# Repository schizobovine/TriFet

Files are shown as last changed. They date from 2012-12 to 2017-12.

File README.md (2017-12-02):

TriFet Motor Driver
-------------------

All credit goes to [Ethan Zonca](http://protofusion.org/), who released the design as Open Source Hardware. Kudos, sir!

Original [TriFet Repository](http://protofusion.org/hg/TriFet/) (Mercurial)

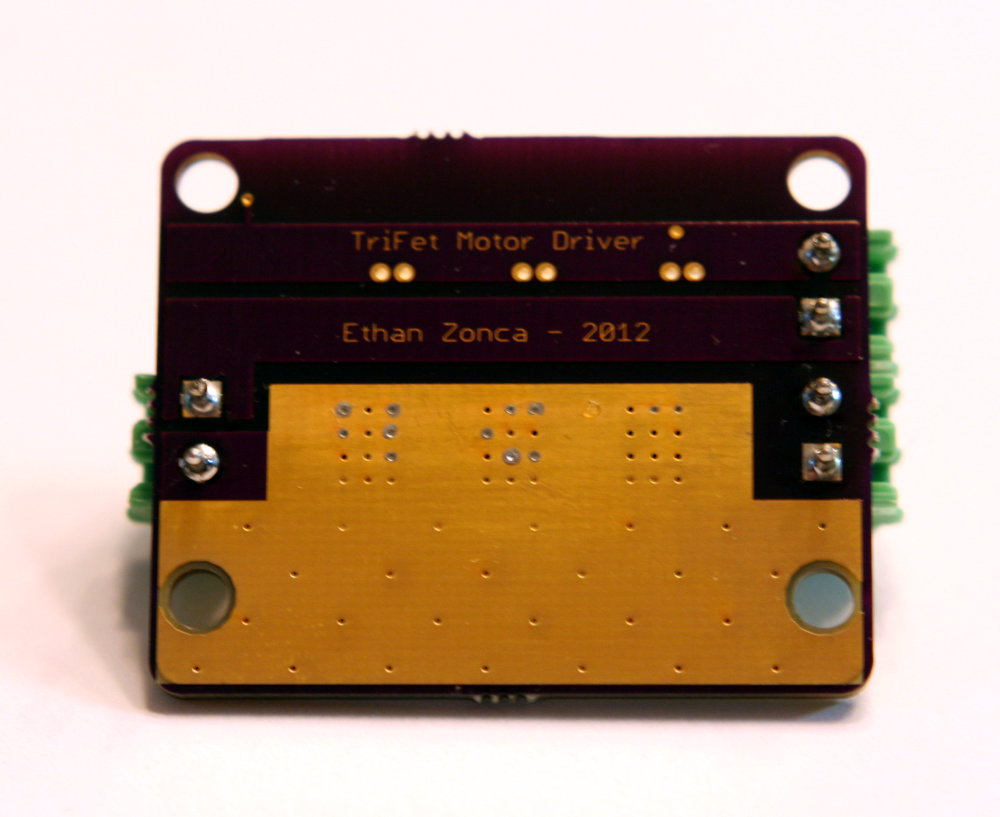
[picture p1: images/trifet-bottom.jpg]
TriFet Bottom

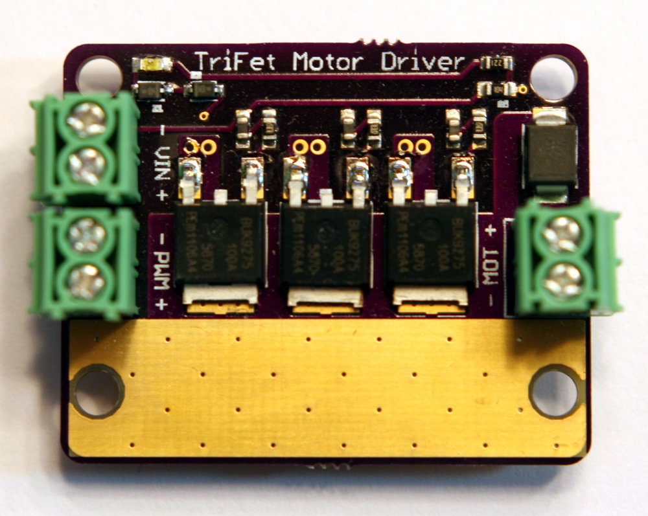
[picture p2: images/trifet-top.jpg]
TriFet Top

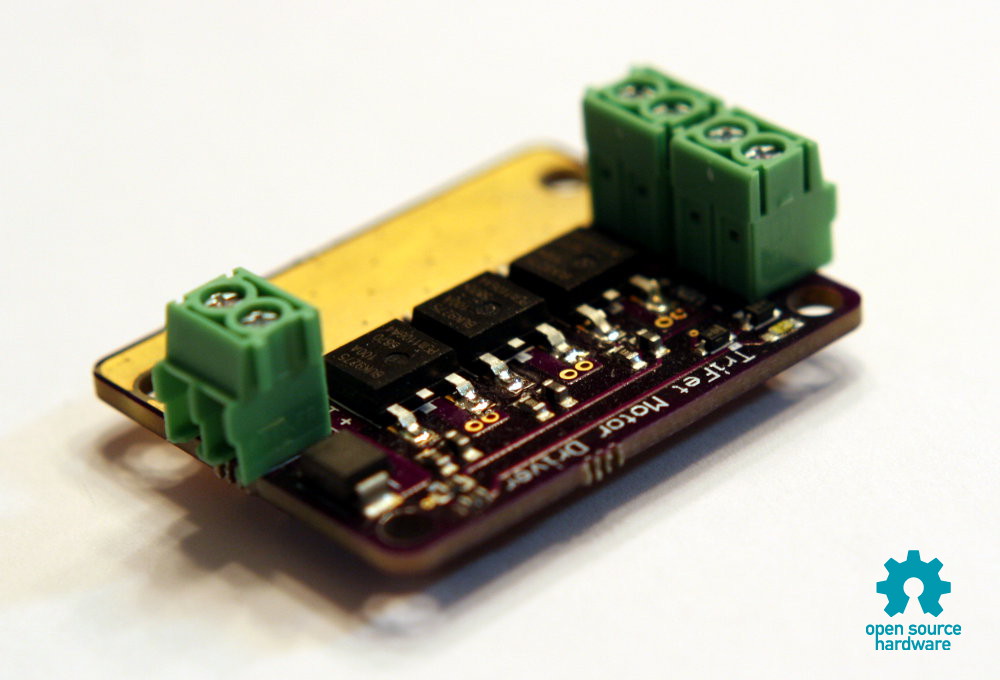
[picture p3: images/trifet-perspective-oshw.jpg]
TriFet Perspective

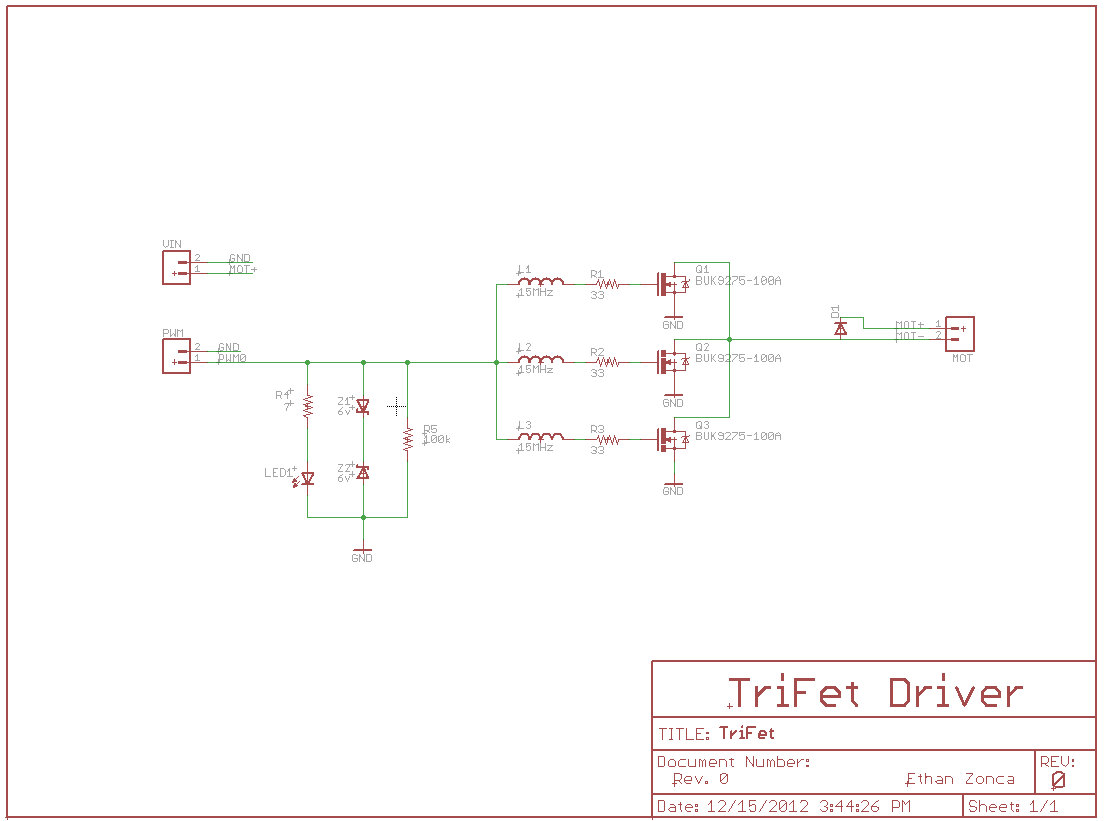
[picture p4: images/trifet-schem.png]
TriFet Schematic


This is my own bit of hacking on it to use as an alternative motor driver for Nerf guns in case my [Polulu High-Power Motor Driver 18v15 (G1)](https://www.pololu.com/product/755) ever lets out the blue smoke. It's special because the G2 drivers all include current choppers, which limits the initial enormous inrush current from the high-power, unprotected RC batteries I'm using (similar to those used in drones). With the current chopper on the VNH5019 (first driver I used), except for absurdly low PWM values, the motor would "warbble" as it kept hitting the limit, backing off, and hitting it again. The G2 custom drivers also include a similar current chopper, hence the desire to avoid it.

I'm trying to optimize for spin-up speed, as the main drawback to motorized Nerf blasters are the noise they make when the flywheels are on. While this could potentially be silenced, it would require a complete overhaul and is sorta out of the realm of a \<\$100 plastic "toy" mod. If I can get \< 1 second spin-up time, I'll probably be happy.

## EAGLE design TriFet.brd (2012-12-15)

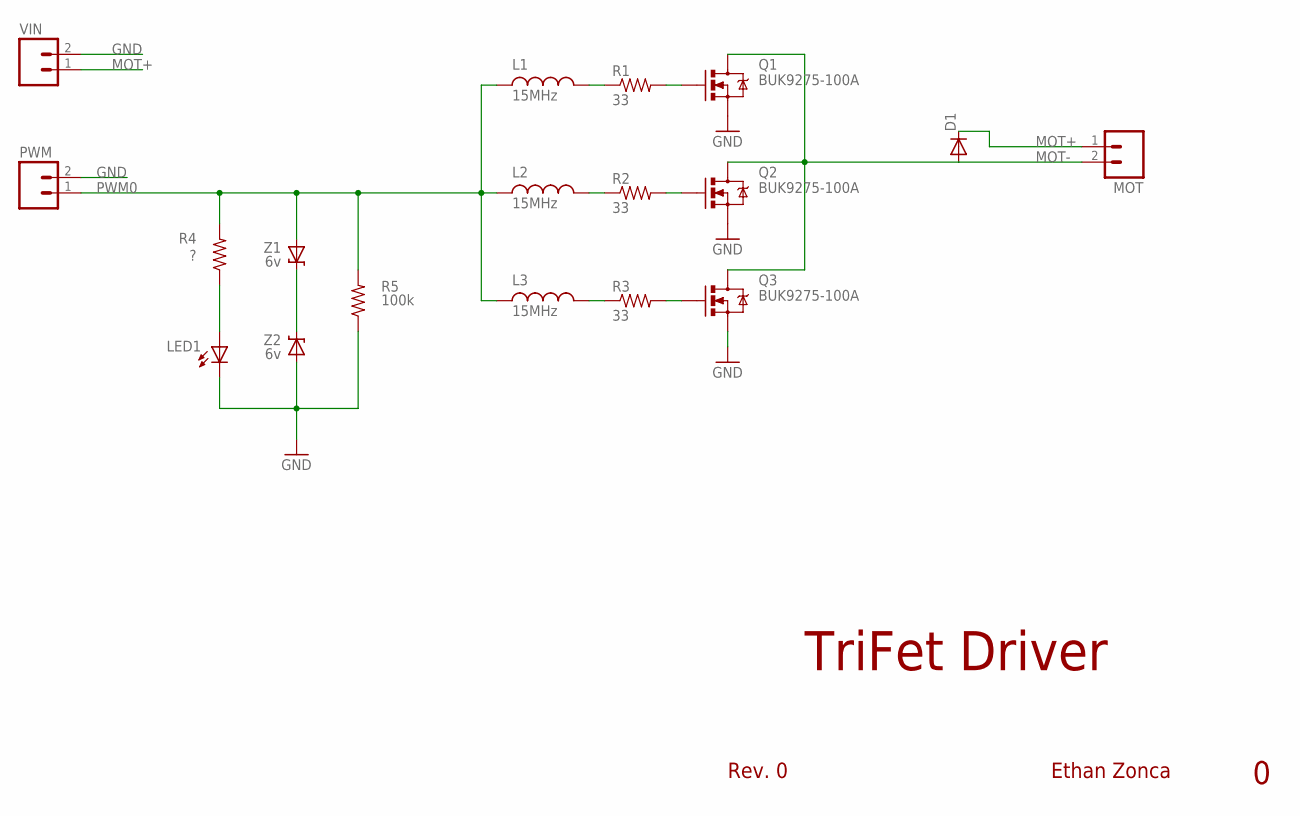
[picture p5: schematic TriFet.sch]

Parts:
D1: DIODESMB; SMB-DIODE
L1, L2, L3: 15MHz; 0603
LED1: LEDCHIP-LED0603; CHIP-LED0603
MOT: M023.5MM; SCREWTERMINAL-3.5MM-2
PWM: M023.5MM-NO_SILK; SCREWTERMINAL-3.5MM-2-NS
Q1, Q2, Q3: BUK9275-100A; DPAK
R1, R2, R3: 33; 0603-RES
R4: ?; 0603-RES
R5: 100k; 0603-RES
VIN: M023.5MM-NO_SILK; SCREWTERMINAL-3.5MM-2-NS
Z1, Z2: 6v; SOD-323

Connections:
GND: LED1.C, PWM.2, Q1.3 (S), Q2.3 (S), Q3.3 (S), R5.1, VIN.2, Z2.2 (A)
MOT+: D1.C, MOT.1, VIN.1
MOT-: D1.A, MOT.2, Q1.4 (D), Q2.4 (D), Q3.4 (D)
unnamed: Q1.1 (G), R1.2
unnamed: L1.2, R1.1
unnamed: LED1.A, R4.1
unnamed: L2.2, R2.1
unnamed: Q2.1 (G), R2.2
unnamed: Z1.1 (C), Z2.1 (C)
unnamed: L3.2, R3.1
unnamed: Q3.1 (G), R3.2
PWM0: L1.1, L2.1, L3.1, PWM.1, R4.2, R5.2, Z1.2 (A)

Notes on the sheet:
TriFet Driver
Rev. 0
Ethan Zonca

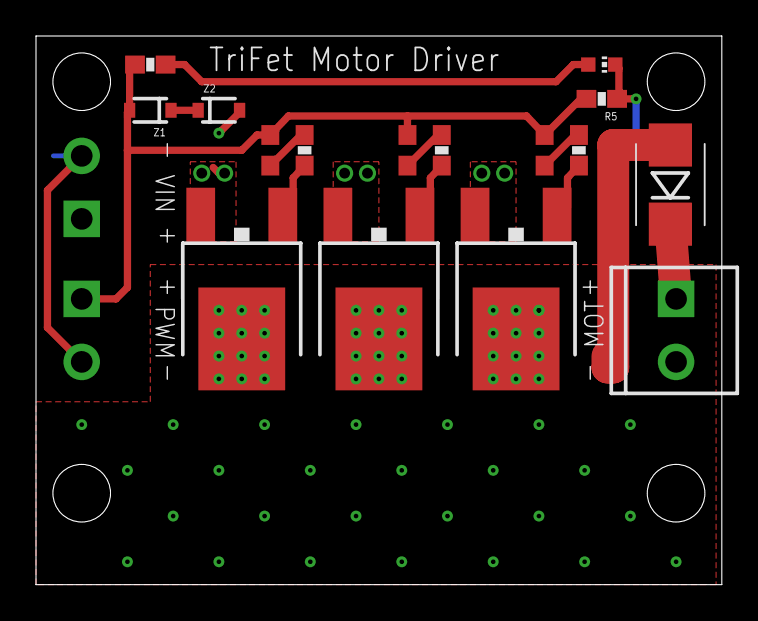
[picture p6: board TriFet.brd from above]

Board: 2 copper layers, 38.1 x 30.5 mm, 18 parts (0 on the bottom side), 12 nets.

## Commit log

2012-12-15 Initial import
    [TriFet.brd, TriFet.sch]
2017-12-02 include images and schematic image from original author

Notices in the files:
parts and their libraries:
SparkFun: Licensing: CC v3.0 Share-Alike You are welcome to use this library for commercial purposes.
